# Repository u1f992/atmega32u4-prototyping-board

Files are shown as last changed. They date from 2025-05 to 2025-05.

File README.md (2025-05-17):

# atmega32u4-prototyping-board

The simple development board featuring only the essential components for the ATmega32U4: bypass capacitors, USB Type-C connector, clock circuit, and a pull-up resistor for RESET.

The VBUS and 5V input lines are separated, allowing you to switch between self-powered and bus-powered modes via external wiring.

- [ATmega32U4 datasheet](https://ww1.microchip.com/downloads/en/DeviceDoc/Atmel-7766-8-bit-AVR-ATmega16U4-32U4_Datasheet.pdf)

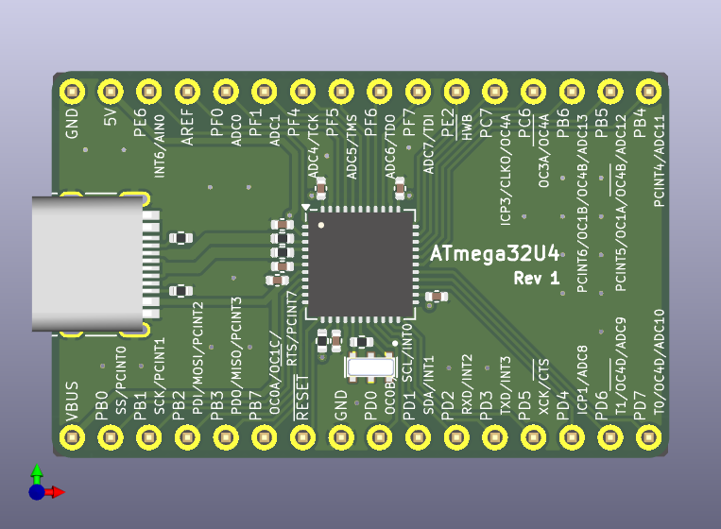
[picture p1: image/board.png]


## Ceramic Resonator Selection

The base part number of the ceramic resonator used in compact Arduino-compatible boards with the ATmega32U4 appears to be Murata's CSTNE16M0V\* ([reference](https://electronics.stackexchange.com/a/665240)). Suitable ceramic resonators can be searched using Murata’s [SimSurfing: IC-タイミングデバイス検索ツール](https://ds.murata.co.jp/simsurfing/ic-timing-device.html). Since the ATmega32U4 itself is not listed, searches were performed using ATmega32M1 and ATmega32C1 instead.

The difference between [CSTNE16M0V53C000R0](https://www.digikey.jp/ja/products/detail/murata-electronics/CSTNE16M0V53C000R0/8747730) and [CSTNE16M0VH3C000R0](https://www.digikey.jp/ja/products/detail/murata-electronics/CSTNE16M0VH3C000R0/8747732) lies in their frequency tolerance, with the latter offering higher precision. The former is more affordable, so it is the one being used.

- [CSTNE16M0V53C000R0|セラミック発振子/水晶振動子|タイミングデバイス|村田製作所](https://www.murata.com/ja-jp/products/productdetail?partno=CSTNE16M0V53C000R0)
- [CSTNE16M0V53C000R0 footprint & symbol by Murata | SnapMagic Search](https://www.snapeda.com/parts/CSTNE16M0V53C000R0/Murata/view-part/)

<details>
<summary>2025-05-09T04:07:26.697Z</summary>
<figure>
<figcaption><a href="https://ds.murata.co.jp/simsurfing/ic-timing-device.html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">ATmega32M1</a></figcaption>

|IC品名|IC備考|ICメーカー|品番|適用用途[^1]|ステータス[^2]|発振周波数\[MHz]|周波数許容偏差|CL1\[pF][^3]|CL2\[pF][^4]|Rf\[ohm]|Rd\[ohm]|IC電圧(min.)\[V]|IC電圧(max.)\[V]|使用温度(min.)\[deg.C]|使用温度(max.)\[deg.C]|IC Application|
|---|---|---|---|:---:|:---:|---|---|---|---|---|---|---|---|---|---|---|
|ATmega32M1|CKSEL:111|Microchip|CSTNE16M0V53C000R0|`APS`|`生産中`|16|+/-0.5%|15|15|Open|0|4.5|5.5|-40|125||
|ATmega32M1|CKSEL:111|Microchip|CSTNE16M0VH3C000R0|`APS`|`生産中`|16|+/-0.07%|15|15|Open|0|4.5|5.5|-40|125||

</figure>

[^1]: <dl><dt><code>CE</code></dt><dd>民生機器</dd><dt><code>IE</code></dt><dd>産業機器</dd><dt><code>AIC</code></dt><dd>自動車用インフォテインメント / コンフォート機器</dd><dt><code>APS</code></dt><dd>自動車用パワートレイン / セーフティ機器</dd><dt><code>MAB</code></dt><dd>医療機器 [GHTF A/B]</dd><dt><code>MC</code></dt><dd>医療機器 [GHTF C]</dd><dt><code>MD</code></dt><dd>医療機器 [GHTF D]</dd><dt><code>MeI</code></dt><dd>インプラント除く医療機器 [GHTF A/B/C]</dd><dt><code>MI</code></dt><dd>インプラント医療機器または医療機器 [GHTF D]</dd><dt><code>MeS</code></dt><dd>インプラント・手術・自動投与用途除く医療機器 [GHTF A/B/C]</dd><dt><code>ME</code></dt><dd>モバイル機器</dd><dt><code>MC</code></dt><dd>モバイル通信</dd><dt><code>IeT</code></dt><dd>運輸・設備・商用エネルギー関連を除く産業機器</dd><dt><code>CDT</code></dt><dd>民生機器-差動伝送</dd><dt><code>HDD</code></dt><dd>HDD</dd><dt><code>DFD</code></dt><dd>重送検知</dd><dt><code>AaM</code></dt><dd>自動車用機器 <a href="https://www.murata.com/contactform?Product=Capacitor">[ムラタへ問合せ要]</a></dd><dt><code>MaM</code></dt><dd>医療機器 <a href="https://www.murata.com/contactform?Product=Capacitor">[ムラタへ問合せ要]</a></dd></dl>
[^2]: <figure><figcaption>「製品ステータス」の説明</figcaption><dl><dt><code>開発中</code></dt><dd>開発中の製品です。サンプル対応可否、量産時期についてはお問い合わせください。</dd><dt><code>生産中</code></dt><dd>量産、販売中の製品です。</dd><dt><code>NRND</code></dt><dd>新モデルへの部品採用を控えていただきたい製品です。<br>(Not Recommended for New Design)</dd><dt><code>生産中止予定</code></dt><dd>生産中止予定の製品であり、最終受注期限及び最終生産時期が表示されている場合があります。<br>最終受注期限までに、必要数量の連絡をお願いします。</dd><dt><code>生産中止</code></dt><dd>生産を中止しており、ご注文を受け付けていない製品です。</dd></dl></figure>
[^3]: 水晶振動子：外付け容量<br>セラロック：内蔵容量
[^4]: 水晶振動子：外付け容量<br>セラロック：内蔵容量

<figure>
<figcaption><a href="https://ds.murata.co.jp/simsurfing/ic-timing-device.html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">ATmega32C1</a></figcaption>

|IC品名|IC備考|ICメーカー|品番|適用用途[^1]|ステータス[^2]|発振周波数\[MHz]|周波数許容偏差|CL1\[pF][^3]|CL2\[pF][^4]|Rf\[ohm]|Rd\[ohm]|IC電圧(min.)\[V]|IC電圧(max.)\[V]|使用温度(min.)\[deg.C]|使用温度(max.)\[deg.C]|IC Application|
|---|---|---|---|:---:|:---:|---|---|---|---|---|---|---|---|---|---|---|
|ATmega32C1|CKSEL:111|Microchip|CSTNE16M0V53C000R0|`APS`|`生産中`|16|+/-0.5%|15|15|Open|0|4.5|5.5|-40|125||
|ATmega32C1|CKSEL:111|Microchip|CSTNE16M0VH3C000R0|`APS`|`生産中`|16|+/-0.07%|15|15|Open|0|4.5|5.5|-40|125||

</figure>
</details>

## License

The design data for this board is provided under the CERN-OHL-S license. However, the symbol, footprint, and 3D model for library/CSTNE16M0V53C000R0 are provided via SnapMagic Search and are licensed under CC BY-SA (Design Exception 1.0) ([reference](https://www.snapeda.com/about/FAQ/#license)).

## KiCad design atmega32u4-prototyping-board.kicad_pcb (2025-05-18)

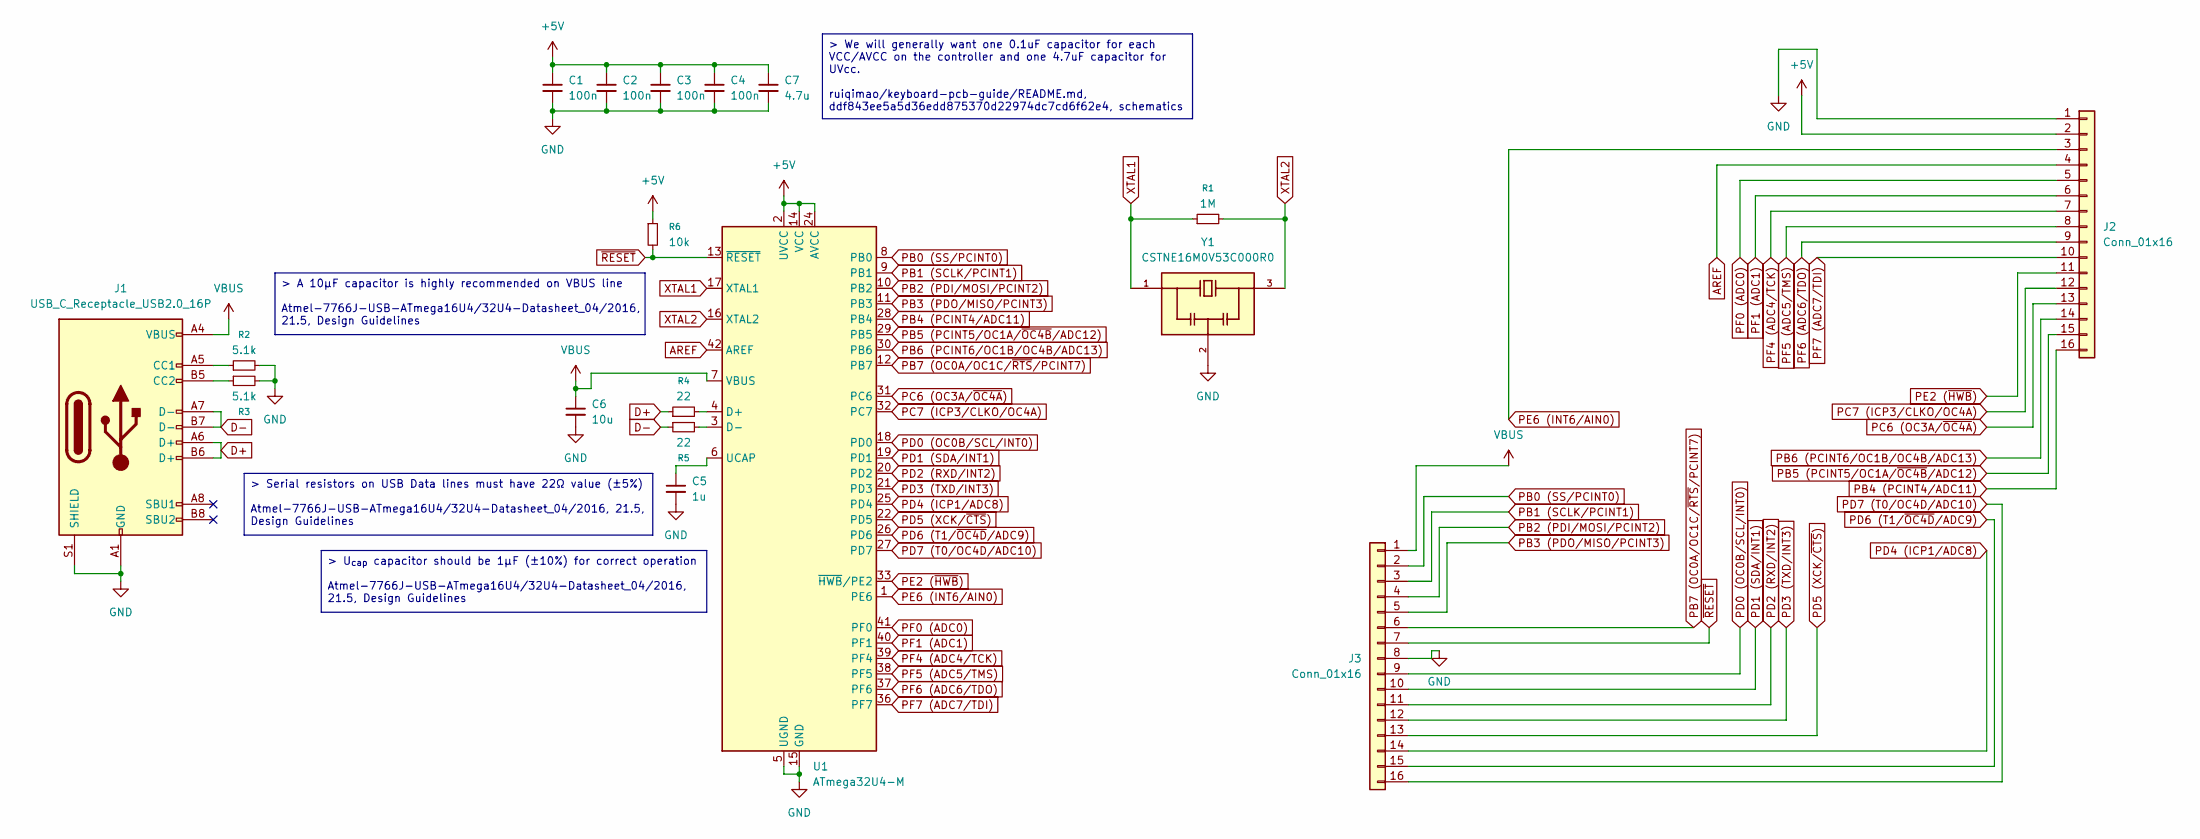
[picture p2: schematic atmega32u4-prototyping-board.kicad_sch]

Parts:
C1, C2, C3, C4: 100n; C_0402_1005Metric
C5: 1u; C_0402_1005Metric
C6: 10u; C_0402_1005Metric
C7: 4.7u; C_0402_1005Metric
J1: USB_C_Receptacle_USB2.0_16P; USB_C_Receptacle_HRO_TYPE-C-31-M-12
J2, J3: Conn_01x16; PinHeader_1x16_P2.54mm_Vertical
R1: 1M; R_0402_1005Metric
R2, R3: 5.1k; R_0402_1005Metric
R4, R5: 22; R_0402_1005Metric
R6: 10k; R_0402_1005Metric
U1: ATmega32U4-M; QFN-44-1EP_7x7mm_P0.5mm_EP5.2x5.2mm
Y1: CSTNE16M0V53C000R0; OSC_CSTNE16M0V53C000R0; PARTREV JGC42-8853B

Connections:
+5V: C1.1, C2.1, C3.1, C4.1, C7.1, J2.2, R6.1, U1.2 (UVCC), U1.14 (VCC), U1.24 (AVCC), U1.34 (VCC), U1.44 (AVCC)
AREF: J2.4, U1.42 (AREF)
D+: J1.A6 (D+), J1.B6 (D+), R4.1
D-: J1.A7 (D-), J1.B7 (D-), R5.1
GND: C1.2, C2.2, C3.2, C4.2, C5.2, C6.2, C7.2, J1.A1 (GND), J1.A12 (GND), J1.B1 (GND), J1.B12 (GND), J1.S1 (SHIELD), J2.1, J3.8, R2.2, R3.2, U1.5 (UGND), U1.15 (GND), U1.23 (GND), U1.35 (GND), U1.43 (GND), U1.45 (GND), Y1.2
unnamed: J1.A5 (CC1), R2.1
unnamed: J1.B5 (CC2), R3.1
unnamed: R4.2, U1.4 (D+)
unnamed: R5.2, U1.3 (D-)
unnamed: C5.1, U1.6 (UCAP)
PB0 (SS/PCINT0): J3.2, U1.8 (PB0)
PB1 (SCLK/PCINT1): J3.3, U1.9 (PB1)
PB2 (PDI/MOSI/PCINT2): J3.4, U1.10 (PB2)
PB3 (PDO/MISO/PCINT3): J3.5, U1.11 (PB3)
PB4 (PCINT4/ADC11): J2.16, U1.28 (PB4)
PB5 (PCINT5/OC1A/~OC4B/ADC12): J2.15, U1.29 (PB5)
PB6 (PCINT6/OC1B/OC4B/ADC13): J2.14, U1.30 (PB6)
PB7 (OC0A/OC1C/~RTS/PCINT7): J3.6, U1.12 (PB7)
PC6 (OC3A/~OC4A): J2.13, U1.31 (PC6)
PC7 (ICP3/CLKO/OC4A): J2.12, U1.32 (PC7)
PD0 (OC0B/SCL/INT0): J3.9, U1.18 (PD0)
PD1 (SDA/INT1): J3.10, U1.19 (PD1)
PD2 (RXD/INT2): J3.11, U1.20 (PD2)
PD3 (TXD/INT3): J3.12, U1.21 (PD3)
PD4 (ICP1/ADC8): J3.14, U1.25 (PD4)
PD5 (XCK/~CTS): J3.13, U1.22 (PD5)
PD6 (T1/~OC4D/ADC9): J3.15, U1.26 (PD6)
PD7 (T0/OC4D/ADC10): J3.16, U1.27 (PD7)
PE2 (~HWB): J2.11, U1.33 (~HWB/PE2)
PE6 (INT6/AIN0): J2.3, U1.1 (PE6)
PF0 (ADC0): J2.5, U1.41 (PF0)
PF1 (ADC1): J2.6, U1.40 (PF1)
PF4 (ADC4/TCK): J2.7, U1.39 (PF4)
PF5 (ADC5/TMS): J2.8, U1.38 (PF5)
PF6 (ADC6/TDO): J2.9, U1.37 (PF6)
PF7 (ADC7/TDI): J2.10, U1.36 (PF7)
VBUS: C6.1, J1.A4 (VBUS), J1.A9 (VBUS), J1.B4 (VBUS), J1.B9 (VBUS), J3.1, U1.7 (VBUS)
XTAL1: R1.1, U1.17 (XTAL1), Y1.1
XTAL2: R1.2, U1.16 (XTAL2), Y1.3
~RESET: J3.7, R6.2, U1.13 (~RESET)

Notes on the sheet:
> A 10µF capacitor is highly recommended on VBUS line Atmel-7766J-USB-ATmega16U4/32U4-Datasheet_04/2016, 21.5, Design Guidelines
> U_{cap} capacitor should be 1µF (±10%) for correct operation Atmel-7766J-USB-ATmega16U4/32U4-Datasheet_04/2016, 21.5, Design Guidelines
> Serial resistors on USB Data lines must have 22Ω value (±5%) Atmel-7766J-USB-ATmega16U4/32U4-Datasheet_04/2016, 21.5, Design Guidelines
> We will generally want one 0.1uF capacitor for each VCC/AVCC on the controller and one 4.7uF capacitor for UVcc. ruiqimao/keyboard-pcb-guide/README.md, ddf843ee5a5d36edd875370d22974dc7cd6f62e4, schematics

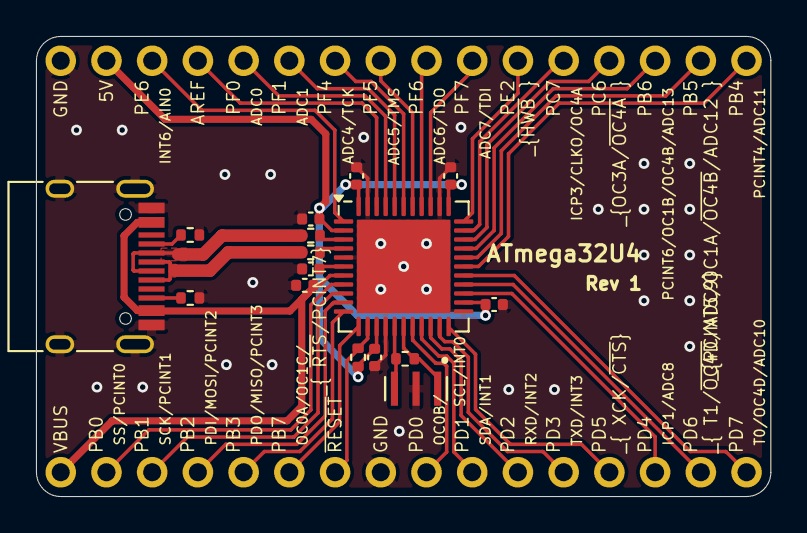
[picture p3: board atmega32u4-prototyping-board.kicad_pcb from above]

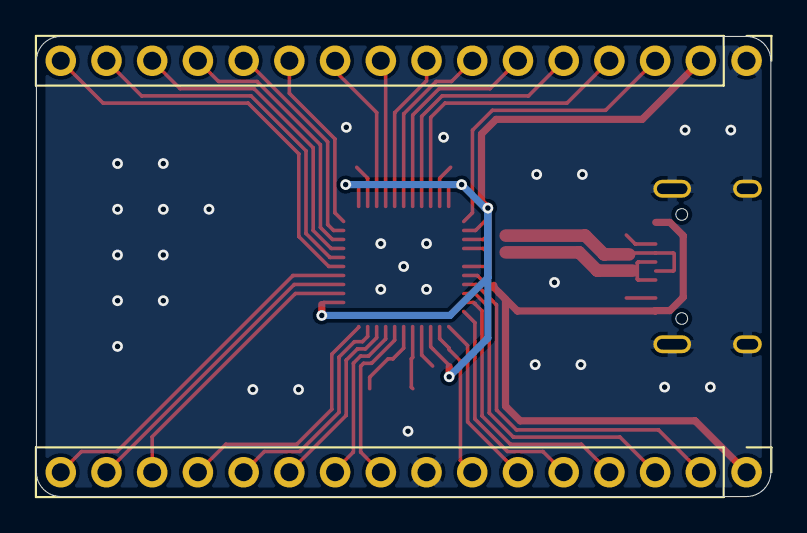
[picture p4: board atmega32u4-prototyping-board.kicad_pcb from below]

Board: 2 copper layers, 40.8 x 25.6 mm, 18 parts (2 on the bottom side), 40 nets.

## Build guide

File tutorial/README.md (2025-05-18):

## 開発環境

```
$ sudo apt install gcc-avr avr-libc avrdude
```

```
# which avr-gcc
/usr/bin/avr-gcc
# avr-gcc -mmcu=atmega32u4 -v -E - < /dev/null
Using built-in specs.
Reading specs from /usr/lib/gcc/avr/7.3.0/device-specs/specs-atmega32u4
COLLECT_GCC=avr-gcc
Target: avr
Configured with: ../gcc/configure -v --enable-languages=c,c++ --prefix=/usr/lib --infodir=/usr/share/info --mandir=/usr/share/man --bindir=/usr/bin --libexecdir=/usr/lib --libdir=/usr/lib --enable-shared --with-system-zlib --enable-long-long --enable-nls --without-included-gettext --disable-libssp --disable-libcc1 --build=x86_64-linux-gnu --host=x86_64-linux-gnu --target=avr --enable-host-pie ASFLAGS= ASFLAGS_FOR_BUILD= CFLAGS='-g -O2 -ffile-prefix-map=/build/gcc-avr-TYLliY/gcc-avr-7.3.0+Atmel3.7.0=. -flto=auto -ffat-lto-objects -fstack-protector-strong -fstack-clash-protection -Wformat  -fcf-protection -fdebug-prefix-map=/build/gcc-avr-TYLliY/gcc-avr-7.3.0+Atmel3.7.0=/usr/src/gcc-avr-1:7.3.0+Atmel3.7.0-1' 'CFLAGS_FOR_BUILD=-g -O2' CPPFLAGS='-Wdate-time -D_FORTIFY_SOURCE=2' CPPFLAGS_FOR_BUILD= CXXFLAGS='-g -O2 -ffile-prefix-map=/build/gcc-avr-TYLliY/gcc-avr-7.3.0+Atmel3.7.0=. -flto=auto -ffat-lto-objects -fstack-protector-strong -fstack-clash-protection -Wformat  -fcf-protection -fdebug-prefix-map=/build/gcc-avr-TYLliY/gcc-avr-7.3.0+Atmel3.7.0=/usr/src/gcc-avr-1:7.3.0+Atmel3.7.0-1' 'CXXFLAGS_FOR_BUILD=-g -O2' DFLAGS=-frelease DFLAGS_FOR_BUILD=-frelease FCFLAGS='-g -O2 -ffile-prefix-map=/build/gcc-avr-TYLliY/gcc-avr-7.3.0+Atmel3.7.0=. -flto=auto -ffat-lto-objects -fstack-protector-strong -fstack-clash-protection -fcf-protection -fdebug-prefix-map=/build/gcc-avr-TYLliY/gcc-avr-7.3.0+Atmel3.7.0=/usr/src/gcc-avr-1:7.3.0+Atmel3.7.0-1' 'FCFLAGS_FOR_BUILD=-g -O2' FFLAGS='-g -O2 -ffile-prefix-map=/build/gcc-avr-TYLliY/gcc-avr-7.3.0+Atmel3.7.0=. -flto=auto -ffat-lto-objects -fstack-protector-strong -fstack-clash-protection -fcf-protection -fdebug-prefix-map=/build/gcc-avr-TYLliY/gcc-avr-7.3.0+Atmel3.7.0=/usr/src/gcc-avr-1:7.3.0+Atmel3.7.0-1' 'FFLAGS_FOR_BUILD=-g -O2' GCJFLAGS=-fdebug-prefix-map=/build/gcc-avr-TYLliY/gcc-avr-7.3.0+Atmel3.7.0=/usr/src/gcc-avr-1:7.3.0+Atmel3.7.0-1 LDFLAGS='-Wl,-Bsymbolic-functions -flto=auto -ffat-lto-objects -Wl,-z,relro' LDFLAGS_FOR_BUILD= OBJCFLAGS='-g -O2 -ffile-prefix-map=/build/gcc-avr-TYLliY/gcc-avr-7.3.0+Atmel3.7.0=. -flto=auto -ffat-lto-objects -fstack-protector-strong -fstack-clash-protection -Wformat  -fcf-protection -fdebug-prefix-map=/build/gcc-avr-TYLliY/gcc-avr-7.3.0+Atmel3.7.0=/usr/src/gcc-avr-1:7.3.0+Atmel3.7.0-1' 'OBJCFLAGS_FOR_BUILD=-g -O2' OBJCXXFLAGS='-g -O2 -ffile-prefix-map=/build/gcc-avr-TYLliY/gcc-avr-7.3.0+Atmel3.7.0=. -flto=auto -ffat-lto-objects -fstack-protector-strong -fstack-clash-protection -Wformat  -fcf-protection -fdebug-prefix-map=/build/gcc-avr-TYLliY/gcc-avr-7.3.0+Atmel3.7.0=/usr/src/gcc-avr-1:7.3.0+Atmel3.7.0-1' 'OBJCXXFLAGS_FOR_BUILD=-g -O2'
Thread model: single
gcc version 7.3.0 (GCC) 
COLLECT_GCC_OPTIONS= '-v' '-E' '-specs=device-specs/specs-atmega32u4' '-mmcu=avr5'
 /usr/lib/gcc/avr/7.3.0/cc1 -E -quiet -v -imultilib avr5 -D__AVR_ATmega32U4__ -D__AVR_DEVICE_NAME__=atmega32u4 - -mn-flash=1 -mno-skip-bug -mmcu=avr5
ignoring nonexistent directory "/usr/lib/gcc/avr/7.3.0/../../../avr/sys-include"
#include "..." search starts here:
#include <...> search starts here:
 /usr/lib/gcc/avr/7.3.0/include
 /usr/lib/gcc/avr/7.3.0/include-fixed
 /usr/lib/gcc/avr/7.3.0/../../../avr/include
End of search list.
# 1 "<stdin>"
# 1 "<built-in>"
# 1 "<command-line>"
# 1 "<stdin>"
COMPILER_PATH=/usr/lib/gcc/avr/7.3.0/:/usr/lib/gcc/avr/7.3.0/:/usr/lib/gcc/avr/:/usr/lib/gcc/avr/7.3.0/:/usr/lib/gcc/avr/:/usr/lib/gcc/avr/7.3.0/../../../avr/bin/
LIBRARY_PATH=/usr/lib/gcc/avr/7.3.0/avr5/:/usr/lib/gcc/avr/7.3.0/../../../avr/lib/avr5/:/usr/lib/gcc/avr/7.3.0/:/usr/lib/gcc/avr/7.3.0/../../../avr/lib/
COLLECT_GCC_OPTIONS= '-v' '-E' '-specs=device-specs/specs-atmega32u4' '-mmcu=avr5'
```

#### .vscode/c_cpp_properties.json

```
{
  "configurations": [
    {
      "name": "AVR",
      "includePath": [
        " /usr/lib/gcc/avr/7.3.0/include/**",
        "/usr/lib/gcc/avr/7.3.0/include-fixed/**",
        "/usr/lib/gcc/avr/7.3.0/../../../avr/include/**"
      ],
      "defines": [
        "F_CPU=16000000UL",
        "__AVR_ATmega32U4__",
        "__AVR_DEVICE_NAME__=atmega32u4"
      ],
      "compilerPath": "/usr/bin/avr-gcc",
      "cStandard": "c89"
    }
  ],
  "version": 4
}
```

## ヒューズ値の確認

[ATmega16U4/32U4 - Complete Datasheet](https://ww1.microchip.com/downloads/en/DeviceDoc/Atmel-7766-8-bit-AVR-ATmega16U4-32U4_Datasheet.pdf), P.354-355「28.2 Fuse Bits」より

<figure>
<figcaption>Low</figcaption>

| | Hex  | CKDIV8 | CKOUT | SUT1 | SUT0 | CKSEL3 | CKSEL2 | CKSEL1 | CKSEL0 |
| --- | ---- | --- | ----- | ---- | ---- | --- | --- | --- | --- |
| ATmega16U4/32U4 | 0x5e | 0 | 1 | 0 | 1 | 1 | 1 | 1 | 0 |
| ATmega16U4RC/32U4RC | 0x52 | | | | | 0 | 0 | | |

<figcaption>High</figcaption>

| | Hex  | OCDEN | JTAGEN | SPIEN | WDTON | EESAVE | BOOTSZ1 | BOOTSZ0 | BOOTRST |
| --- | ---- | ----- | --- | ----- | ----- | --- | --- | --- | --- |
| ATmega16U4/32U4 | 0x99 | 1 | 0 | 0 | 1 | 1 | 0 | 0 | 1 |
| ATmega16U4RC/32U4RC | | | | | | | | | |

<figcaption>Extended</figcaption>

| | Hex  | x | x | x | x | HWBE | BODLEVEL2 | BODLEVEL1 | BODLEVEL0 |
| --- | ---- | --- | --- | --- | --- | ---- | --- | --- | --- |
| ATmega16U4/32U4 | 0xf3 | 1 | 1 | 1 | 1 | 0 | 0 | 1 | 1 |
| ATmega16U4RC/32U4RC | 0xfb | | | | | 1 | | | |

</figure>

```
$ avrdude -c usbasp -p m32u4 -U lfuse:r:-:h -U hfuse:r:-:h -U efuse:r:-:h

avrdude: AVR device initialized and ready to accept instructions
avrdude: device signature = 0x1e9587 (probably m32u4)
avrdude: reading lfuse memory ...
avrdude: writing output file <stdout>
0x5e
avrdude: reading hfuse memory ...
avrdude: writing output file <stdout>
0x99
avrdude: reading efuse memory ...
avrdude: writing output file <stdout>
0xf3

avrdude done.  Thank you.
```

当然だが今回のATmega32U4はデフォルト通りのようだ。

## ヒューズ値の設定

https://osamuaoki.github.io/jp/2020/03/29/atmega32u4-2/

> CKDIV8は出荷時にプログラムされている(=0)がTeensyの設定でも採用 されています。一見チョット不安になりましたが、実際にはスタート アップコードにCLKPR = 0x80;CLKPR = 0;を置くのがTeensyの標準の ようで分周を1に戻すのでので、これは問題ないとみました。
> 
> まず、5V 16 MHz Crystal使用でBODをするから、以下確定です(P30,P31)。
> 
> - CKSEL0 = 1
> - SUT1..0 = 01
> - CKSEL3..1 = 111

| | Hex  | CKDIV8 | CKOUT | SUT1 | SUT0 | CKSEL3 | CKSEL2 | CKSEL1 | CKSEL0 |
| --- | ---- | --- | ----- | ---- | ---- | --- | --- | --- | --- |
| ATmega16U4/32U4 | 0x5f | 0 | 1 | 0 | 1 | 1 | 1 | 1 | 1 |

低速スタートアップにしておく必要がないので`CKDIV8=1`か？

| | Hex  | CKDIV8 | CKOUT | SUT1 | SUT0 | CKSEL3 | CKSEL2 | CKSEL1 | CKSEL0 |
| --- | ---- | --- | ----- | ---- | ---- | --- | --- | --- | --- |
| ATmega16U4/32U4 | 0xdf | 1 | 1 | 0 | 1 | 1 | 1 | 1 | 1 |
